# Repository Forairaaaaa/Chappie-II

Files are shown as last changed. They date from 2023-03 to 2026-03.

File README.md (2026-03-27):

# Chappie-II

基于ESP32的简易掌上终端~

视频介绍：https://www.bilibili.com/video/BV1QL411S7jo

硬件开源链接：https://oshwhub.com/eda_rgprdhwej/chappie2

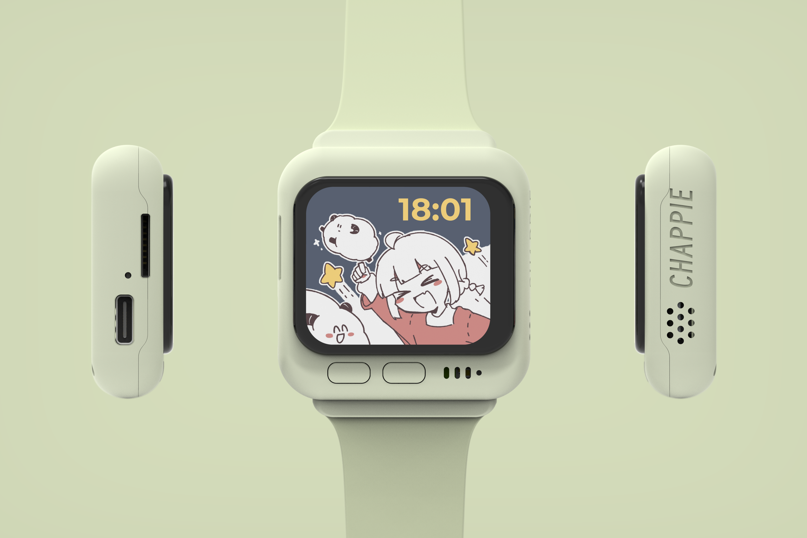
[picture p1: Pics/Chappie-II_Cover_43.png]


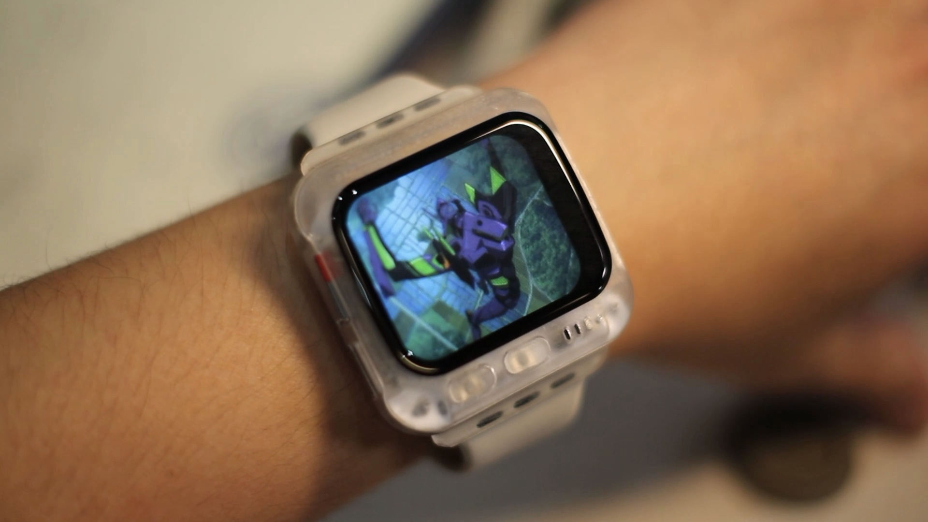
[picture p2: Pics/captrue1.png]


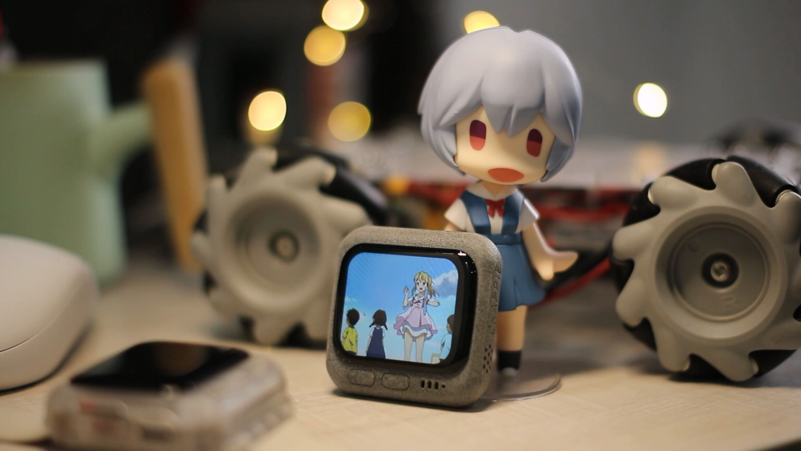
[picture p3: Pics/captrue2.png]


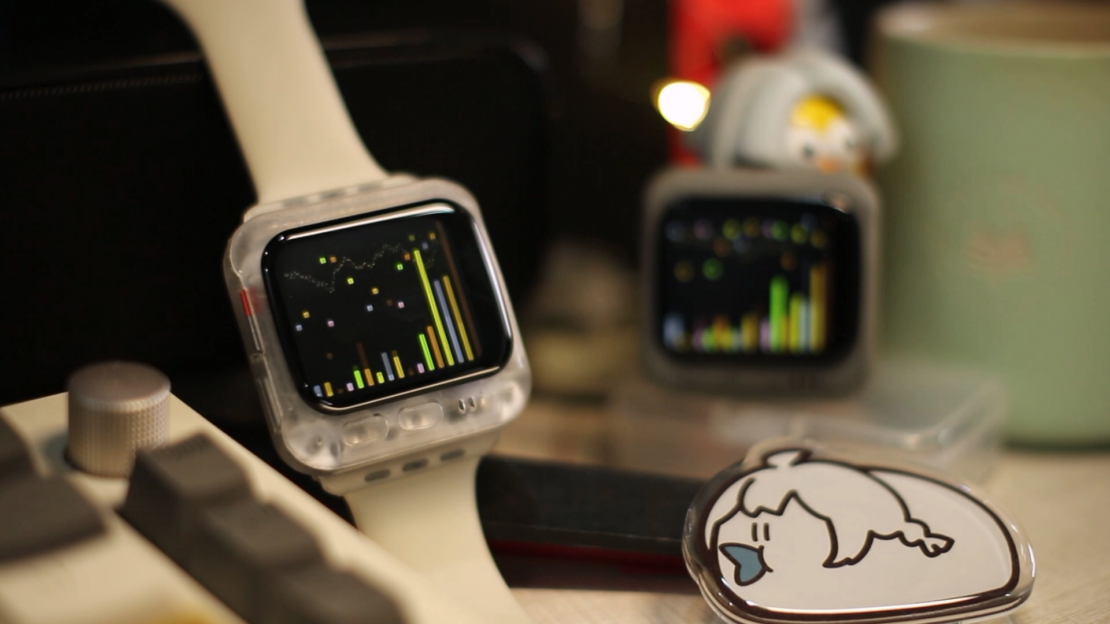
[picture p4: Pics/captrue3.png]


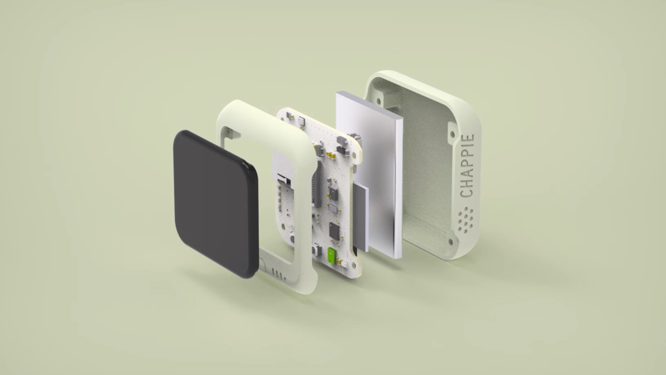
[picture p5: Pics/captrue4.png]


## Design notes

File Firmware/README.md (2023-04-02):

工程为PIO工程，vscode安装PIO扩展后打开文件夹即可

#### 文件树

```
Chappie-II/
├── default_16MB.csv
├── lib
│   ├── arduinoFFT
│   ├── ESP32-BLE-Gamepad
│   ├── FastLED
│   ├── LovyanGFX
│   ├── lv_conf.h
│   ├── lvgl
│   ├── NimBLE-Arduino
│   └── README
├── platformio.ini
├── src
    ├── ChappieBsp
    ├── ChappieUI
    └── main.cpp

```

#### 下载依赖

```shell
git submodule init
git submodule update
```

```shell
cd lib
git clone https://github.com/lovyan03/LovyanGFX.git
git clone -b v8.3.5 https://github.com/lvgl/lvgl.git
git clone https://github.com/FastLED/FastLED.git
git clone https://github.com/lemmingDev/ESP32-BLE-Gamepad.git
git clone https://github.com/h2zero/NimBLE-Arduino.git
git clone https://github.com/kosme/arduinoFFT.git
```

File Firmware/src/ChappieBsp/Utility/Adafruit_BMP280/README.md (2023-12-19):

# Adafruit BMP280 Driver (Barometric Pressure Sensor) 

This driver is for the [Adafruit BMP280 Breakout](http://www.adafruit.com/products/2651)



## About the BMP280 ##

This precision sensor from Bosch is the best low-cost sensing solution for measuring barometric pressure and temperature. Because pressure changes with altitude you can also use it as an altimeter!

## About this Driver ##

Adafruit invests time and resources providing this open source code.  Please support Adafruit and open-source hardware by purchasing products from Adafruit!

Written by Kevin (KTOWN) Townsend for Adafruit Industries.

<!-- START COMPATIBILITY TABLE -->

## Compatibility

MCU                | Tested Works | Doesn't Work | Not Tested  | Notes
------------------ | :----------: | :----------: | :---------: | -----
Atmega328 @ 16MHz  |      X       |             |            |
Atmega328 @ 12MHz  |      X       |             |            |
Atmega32u4 @ 16MHz |      X       |             |            | Use SDA/SCL on pins D2 &amp; D3
Atmega32u4 @ 8MHz  |      X       |             |            | Use SDA/SCL on pins D2 &amp; D3
ESP8266            |      X       |             |            | SDA/SCL default to pins 4 &amp; 5 but any two pins can be assigned as SDA/SCL using Wire.begin(SDA,SCL)
Atmega2560 @ 16MHz |      X       |             |            | Use SDA/SCL on pins 20 &amp; 21
ATSAM3X8E          |      X       |             |            | Use SDA/SCL on pins 20 &amp; 21
ATSAM21D           |      X       |             |            |
ATtiny85 @ 16MHz   |             |      X       |            |
ATtiny85 @ 8MHz    |             |      X       |            |
Intel Curie @ 32MHz |             |             |     X       |
STM32F2            |             |             |     X       |

  * ATmega328 @ 16MHz : Arduino UNO, Adafruit Pro Trinket 5V, Adafruit Metro 328, Adafruit Metro Mini
  * ATmega328 @ 12MHz : Adafruit Pro Trinket 3V
  * ATmega32u4 @ 16MHz : Arduino Leonardo, Arduino Micro, Arduino Yun, Teensy 2.0
  * ATmega32u4 @ 8MHz : Adafruit Flora, Bluefruit Micro
  * ESP8266 : Adafruit Huzzah
  * ATmega2560 @ 16MHz : Arduino Mega
  * ATSAM3X8E : Arduino Due
  * ATSAM21D : Arduino Zero, M0 Pro
  * ATtiny85 @ 16MHz : Adafruit Trinket 5V
  * ATtiny85 @ 8MHz : Adafruit Gemma, Arduino Gemma, Adafruit Trinket 3V

<!-- END COMPATIBILITY TABLE -->

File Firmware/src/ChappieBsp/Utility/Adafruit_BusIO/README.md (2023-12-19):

# Adafruit Bus IO Library 

This is a helper library to abstract away I2C & SPI transactions and registers

Adafruit invests time and resources providing this open source code, please support Adafruit and open-source hardware by purchasing products from Adafruit!

MIT license, all text above must be included in any redistribution

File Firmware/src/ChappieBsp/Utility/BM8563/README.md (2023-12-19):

Thanks to: https://github.com/tanakamasayuki/I2C_BM8563.git

# I2C BM8563 RTC Library

This is a library of BM8563, the RTC for I2C connectivity.

## Support Devices

- [M5Stack M5Stick](https://docs.m5stack.com/#/en/core/m5stickc)
- [M5Stack M5Stick Plus](https://docs.m5stack.com/#/en/core/m5stickc_plus)
- [M5Stack Core2](https://docs.m5stack.com/#/en/core/core2)
- [M5Stack Timer Camera](https://docs.m5stack.com/#/en/unit/timercam)
- [M5Stack Timer Camera X](https://docs.m5stack.com/#/en/unit/timercam_x)
- [M5Stack CoreInk](https://docs.m5stack.com/#/en/core/coreink)

## Usage
```c
#include "I2C_BM8563.h"
#include <WiFi.h>

// RTC BM8563 I2C port
// I2C pin definition for M5Stick & M5Stick Plus & M5Stack Core2 & M5Stack Core.Ink
#define BM8563_I2C_SDA 21
#define BM8563_I2C_SCL 22

// I2C pin definition for M5Stack TimerCam
// #define BM8563_I2C_SDA 12
// #define BM8563_I2C_SCL 14

I2C_BM8563 rtc(I2C_BM8563_DEFAULT_ADDRESS, Wire1);

const char* ntpServer = "time.cloudflare.com";

void setup() {
  // Init Serial
  Serial.begin(115200);
  delay(50);

  // Connect to an access point
  WiFi.begin();                 // Connect to the access point of the last connection
  //WiFi.begin("SSID", "KEY");  // Or, Connect to the specified access point

  Serial.print("Connecting to Wi-Fi ");
  while (WiFi.status() != WL_CONNECTED) {
    delay(500);
    Serial.print(".");
  }
  Serial.println(" CONNECTED");

  // Set ntp time to local
  configTime(9 * 3600, 0, ntpServer);

  // Init I2C
  Wire1.begin(BM8563_I2C_SDA, BM8563_I2C_SCL);

  // Init RTC
  rtc.begin();

  // Get local time
  struct tm timeInfo;
  if (getLocalTime(&timeInfo)) {
    // Set RTC time
    I2C_BM8563_TimeTypeDef timeStruct;
    timeStruct.hours   = timeInfo.tm_hour;
    timeStruct.minutes = timeInfo.tm_min;
    timeStruct.seconds = timeInfo.tm_sec;
    rtc.setTime(&timeStruct);

    // Set RTC Date
    I2C_BM8563_DateTypeDef dateStruct;
    dateStruct.weekDay = timeInfo.tm_wday;
    dateStruct.month   = timeInfo.tm_mon + 1;
    dateStruct.date    = timeInfo.tm_mday;
    dateStruct.year    = timeInfo.tm_year + 1900;
    rtc.setDate(&dateStruct);
  }
}

void loop() {
  I2C_BM8563_DateTypeDef dateStruct;
  I2C_BM8563_TimeTypeDef timeStruct;

  // Get RTC
  rtc.getDate(&dateStruct);
  rtc.getTime(&timeStruct);

  // Print RTC
  Serial.printf("%04d/%02d/%02d %02d:%02d:%02d\n",
                dateStruct.year,
                dateStruct.month,
                dateStruct.date,
                timeStruct.hours,
                timeStruct.minutes,
                timeStruct.seconds
               );

  // Wait
  delay(1000);
}
```

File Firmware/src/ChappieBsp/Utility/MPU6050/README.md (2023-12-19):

Thanks to: https://github.com/ElectronicCats/mpu6050.git



# MPU6050 by Electronic Cats

MPU-6050 6-axis accelerometer/gyroscope Arduino Library
adapted for Arduino Library Manager by Electronic Cats, Feb 2019

The MPU6050 combines a 3-axis gyroscope and a 3-axis accelerometer on the same silicon die together with
an onboard Digital Motion Processor(DMP) which processes complex 6-axis MotionFusion algorithms.

### Quick Installing

To install, use the Arduino Library Manager and search for "mpu6050" and install the library.

### Manual Installing
To install this library:

 - install it using the Arduino Library manager ("Sketch" -> "Include
   Library" -> "Manage Libraries..."), or
 - download a zipfile from github using the "Download ZIP" button and
   install it using the IDE ("Sketch" -> "Include Library" -> "Add .ZIP
   Library..."
 - clone this git repository into your sketchbook/libraries folder.

For more info, see https://www.arduino.cc/en/Guide/Libraries

## Features of this version

- Support for SAMD21 or ARM
- Support ESP32 and ESP8266
- Support for SAM

### Original Library

Based in the work of [jrowberg/i2cdevlib](https://github.com/jrowberg/i2cdevlib/tree/master/Arduino/MPU6050)

### Maintainer

<a href="https://github.com/sponsors/ElectronicCats">
  
</a>

Electronic Cats invests time and resources providing this open source design, please support Electronic Cats and open-source hardware by purchasing products from Electronic Cats!

### License

MIT

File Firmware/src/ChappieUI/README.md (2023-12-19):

# ChappieUI

基于[Lvgl](https://github.com/lvgl/lvgl)及[ChappieBsp](https://github.com/Forairaaaaa/ChappieBsp)的简单UI框架，UI框架实现简单App管理，启动器实现基础界面及App图形入口

使用`App_Generator.py`即可一键生成App：

```shell
python ./App_Generator.py
```

#### 文件树

```
ChappieUI/
├── Apps
│   ├── App_Dino
│   ├── App_ESPNOW
│   ├── App_FFT
│   ├── App_Gamepad
│   ├── App_Generator.py
│   ├── AppRegister.h
│   ├── App_Settings
│   ├── App_StupidSnake
│   ├── AppTypedef.h
│   ├── App_Watch
│   ├── App_WifiTV
│   └── Resource
├── ChappieUIConfigs.h
├── ChappieUI.cpp
├── ChappieUI.h
├── Launcher
    ├── App_Launcher.cpp
    ├── App_Launcher.h
    └── UI
```

#### App结构

```c++
/* App名字 */
std::string App_Template_appName();

/* App图标 */
void* App_Template_appIcon();

/* App创建回调 */
void App_Template_onCreate();

/* App循环回调 */
void App_Template_onLoop();

/* App结束回调 */
void App_Template_onDestroy();
```

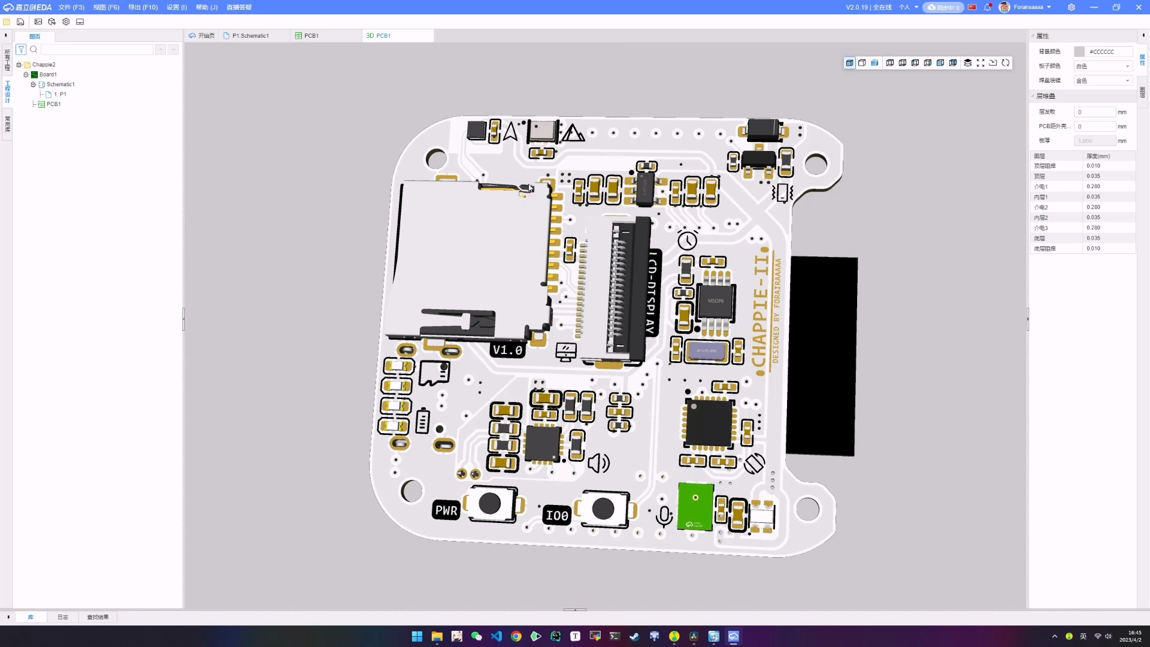
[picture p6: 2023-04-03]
Pics/captrue5.png

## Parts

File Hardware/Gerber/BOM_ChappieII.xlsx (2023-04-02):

No. | Quantity | Comment | Designator | Footprint | Value | Manufacturer Part | Manufacturer | Supplier Part | Supplier
1 | 2 | 47uF | C1,C6 | C0603 | 47uF | GRM188R60J476ME15D | muRata(村田) | C140782 | LCSC
2 | 7 | 22uF | C2,C7,C9,C10,C11,C12,C23 | C0603 | 22uF | CL10A226MP8NUNE | SAMSUNG(三星) | C86295 | LCSC
3 | 13 | 100nF | C3,C8,C13,C18,C19,C20,C21,C22,C24,C26,C28,C30,C33 | C0402 | 100nF | CC0402KRX7R7BB104 | YAGEO(国巨) | C60474 | LCSC
4 | 5 | 10uF | C4,C5,C16,C17,C25 | C0603 | 10uF | CL10A106KP8NNNC | SAMSUNG(三星) | C19702 | LCSC
5 | 2 | 18pF | C14,C15 | C0402 | 18pF | 0402CG180J500NT | FH(风华) | C1549 | LCSC
6 | 1 | 10nF | C27 | C0402 | 10nF | CC0402KRX7R9BB103 | YAGEO(国巨) | C60133 | LCSC
7 | 1 | 2.2nF | C29 | C0402 | 2.2nF | 0402B222K500NT | FH(风华) | C1531 | LCSC
8 | 2 | 220pF | C31,C32 | C0603 | 220pF | CL10B221KB8NNNC | SAMSUNG(三星) | C1603 | LCSC
9 | 1 | TF-01A | CARD1 | TF-SMD_TF-01A |  | TF-01A | 韩国韩荣 | C91145 | LCSC
10 | 1 | HC-1.25-2PWT | CN1 | CONN-SMD_2P-P1.25-HC-1.25-2PWT |  | HC-1.25-2PWT | HCTL(华灿天禄) | C2845379 | LCSC
11 | 1 | M1250R-02P | CN2 | CONN-TH_2P-P1.25_L4.7-W4.3 |  | M1250R-02P | XFCN(兴飞) | C481436 | LCSC
12 | 1 | USBLC6-2SC6 | D1 | SOT-23-6_L2.9-W1.6-P0.95-LS2.8-BL |  | USBLC6-2SC6 | TECH PUBLIC(台舟) | C2827654 | LCSC
13 | 1 | 1N4148W-7-F | D2 | SOD-123_L2.7-W1.6-LS3.7-RD-1 |  | 1N4148W-7-F | DIODES(美台) | C83528 | LCSC
14 | 1 | FPC-05F-18PH20 | FPC1 | FPC-SMD_18P-P0.50_FPC-05F-18PH20 |  | FPC-05F-18PH20 | XUNPU(讯普) | C2856802 | LCSC
15 | 2 | B-2202N20P-B121 | H1,H2 | HDR-SMD_20P-P2.00-V-R2-C10-S2.00-S6.0 |  | B-2202N20P-B121 | Ckmtw(灿科盟) | C135211 | LCSC
16 | 2 | TS-1088-AR02016 | KEY_DWN,KEY_PWR | SW-SMD_L4.0-W2.9-LS5.0 |  | TS-1088-AR02016 | XUNPU(讯普) | C720477 | LCSC
17 | 1 | TS24CA | KEY_RST | SW-SMD_TS24CA |  | TS24CA | SHOU HAN(首韩) | C393942 | LCSC
18 | 1 | 1uH | L1 | IND-SMD_L4.4-W4.2 | 1uH | MWSA0402S-1R0MT | Sunlord(顺络) | C408332 | LCSC
19 | 2 | 22uH | L2,L3 | L0603 | 22uH | CMI160808J220KT | FH(风华) | C361669 | LCSC
20 | 1 | WS2812B-2020 | LED1 | LED-SMD_4P-L2.0-W2.0-TL_WS2812B-2020 |  | WS2812B-2020 | worldsemi | C965555 | LCSC
21 | 1 | Z3OC1T8219731 | M1 | VIBRATING-MOTOR-SMD_3P-C9900001680 |  | Z3OC1T8219731 | KOTL(金龙机电) | C2894731 | LCSC
22 | 1 | MSM261D4030H1CPM | MIC1 | MIC-SMD_8P-L4.0-W3.0_ZTS6231 |  | MSM261D4030H1CPM | MEMS(敏芯微) | C966942 | LCSC
23 | 4 | MHT192WDT-ICE | PWR_D1,PWR_D2,PWR_D3,PWR_D4 | LED0603-RD |  | MHT192WDT-ICE | MEIHUA(美华) | C389522 | LCSC
24 | 2 | AO3400A | Q1,Q2 | SOT-23-3_L2.9-W1.3-P1.90-LS2.4-BR |  | AO3400A | HUASHUO(华朔) | C700953 | LCSC
25 | 2 | 5.1kΩ | R1,R4 | R0402 | 5.1kΩ | 0402WGF5101TCE | UNI-ROYAL(厚声) | C25905 | LCSC
26 | 1 | 2Ω | R2 | R0402 | 2Ω | 0402WGF200KTCE | UNI-ROYAL(厚声) | C270630 | LCSC
27 | 1 | 100kΩ | R3 | R0402 | 100kΩ | RC0402FR-07100KL | YAGEO(国巨) | C60491 | LCSC
28 | 9 | 10kΩ | R5,R7,R11,R12,R13,R14,R15,R17,R23 | R0402 | 10kΩ | TR0402D10K0Q1025Z | EVER OHMS(天二科技) | C149898 | LCSC
29 | 1 | 500mΩ | R6 | R0603 | 500mΩ | 0603WAF500LT5E | UNI-ROYAL(厚声) | C45312 | LCSC
30 | 1 | 200kΩ | R8 | R0402 | 200kΩ | 0402WGF2003TCE | UNI-ROYAL(厚声) | C25764 | LCSC
31 | 1 | 100kΩ | R9 | R0402 | 100kΩ | 0402WGF1003TCE | UNI-ROYAL(厚声) | C25741 | LCSC
32 | 3 | 0Ω | R10,R19,R20 | R0603 | 0Ω | 0603WAF0000T5E | UNI-ROYAL(厚声) | C21189 | LCSC
33 | 1 | 10Ω | R16 | R0402 | 10Ω | 0402WGF100JTCE | UNI-ROYAL(厚声) | C25077 | LCSC
34 | 1 | 10Ω | R18 | R0603 | 10Ω | 0603WAF100JT5E | UNI-ROYAL(厚声) | C22859 | LCSC
35 | 1 | 1MΩ | R21 | R0603 | 1MΩ | SCR0603J1M | VO(翔胜) | C3017671 | LCSC
36 | 2 | 2.2kΩ | R22,R24 | R0402 | 2.2kΩ | 0402WGF2201TCE | UNI-ROYAL(厚声) | C25879 | LCSC
37 | 1 | AP2112K-3.3TRG1 | U1 | SOT-25-5_L3.0-W1.8-P0.95-LS3.0-BR |  | AP2112K-3.3TRG1 | DIODES(美台) | C51118 | LCSC
38 | 1 | IP5306 | U2 | ESOP-8_L4.9-W3.9-P1.27-LS6.0-BL-EP |  | IP5306 | INJOINIC(英集芯) | C181692 | LCSC
39 | 1 | BM8563EMA | U3 | MSOP-8_L3.0-W3.0-P0.65-LS5.0-BL |  | BM8563EMA | GATEMODE(捷茂微) | C269878 | LCSC
40 | 1 | BMM150 | U4 | WLCSP-12_L1.6-W1.6_BMM150 |  | BMM150 | Bosch(博世) | C171681 | LCSC
41 | 1 | BMP280 | U5 | WLGA-8_L2.5-W2.0-P0.65-TR_DPS422 |  | BMP280 | Bosch(博世) | C83291 | LCSC
42 | 1 | ESP32-S3-WROOM-1(N16R2) | U6 | WIRELM-SMD_ESP32-S3-WROOM-1 |  | ESP32-S3-WROOM-1(N16R2) | ESPRESSIF(乐鑫) | C2913205 | LCSC
43 | 1 | MAX98357AETE+T | U7 | TQFN-16_L3.0-W3.0-P0.50-BL-EP1.5 |  | MAX98357AETE+T | MAXIM(美信) | C910544 | LCSC
44 | 1 | MPU-6050 | U8 | QFN-24_L4.0-W4.0-P0.50-BL-EP2.7 |  | MPU-6050 | TDK InvenSense(应美盛) | C24112 | LCSC
45 | 1 | KH-TYPE-C-16P | USB1 | USB-C-SMD_KH-TYPE-C-16P |  | KH-TYPE-C-16P | kinghelm(金航标) | C709357 | LCSC
46 | 1 | 32.768kHz | X1 | OSC-SMD_L3.2-W1.5 | 32.768kHz | FC-135 32.7680KA-A | EPSON(爱普生) | C1669857 | LCSC

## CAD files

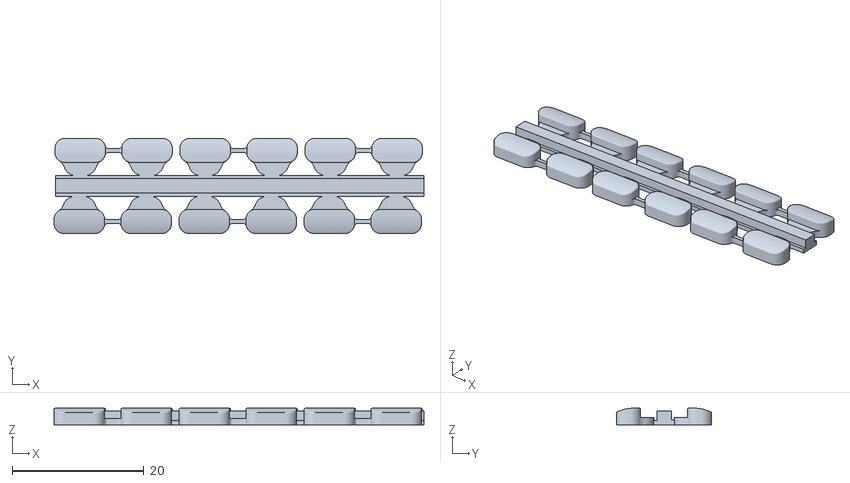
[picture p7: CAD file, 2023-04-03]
Modles/Chappie-II-button.stl
56.2 x 14.5 x 2.55

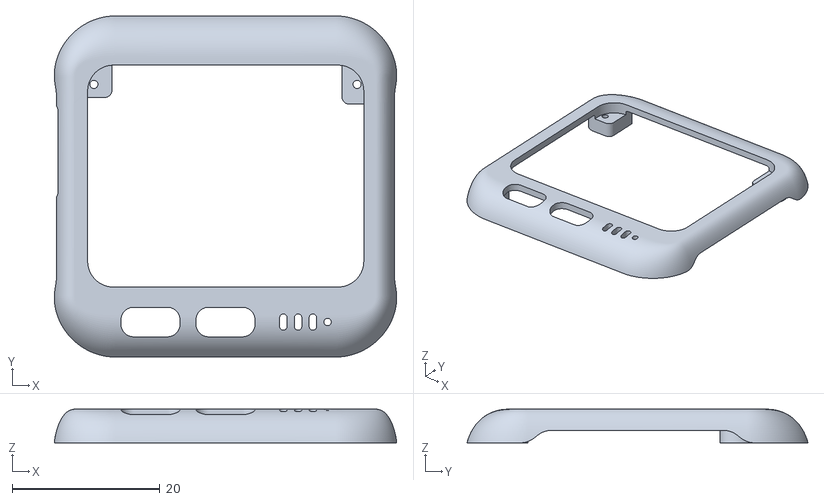
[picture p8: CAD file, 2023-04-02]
Modles/Chappie-II-top.stl
46.4 x 46.2 x 4.56

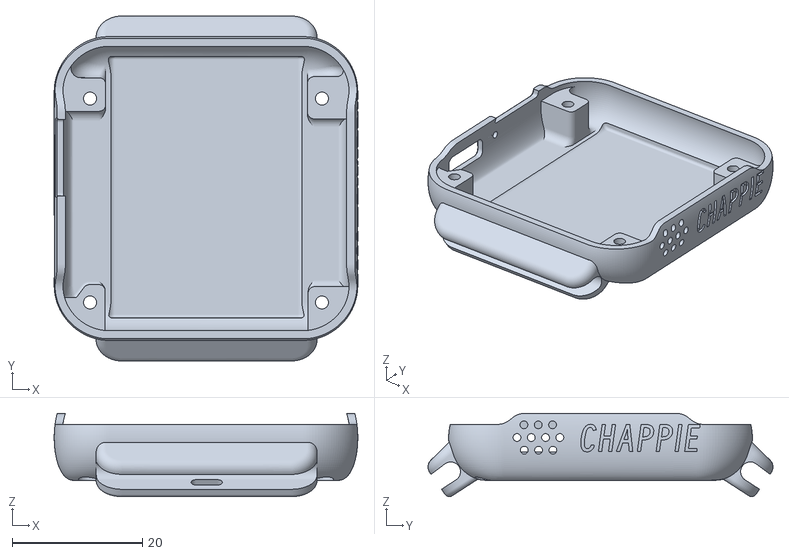
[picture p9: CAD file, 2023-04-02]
Modles/Chappie-II-bottom-watch.stl
46.7 x 53.1 x 12.8

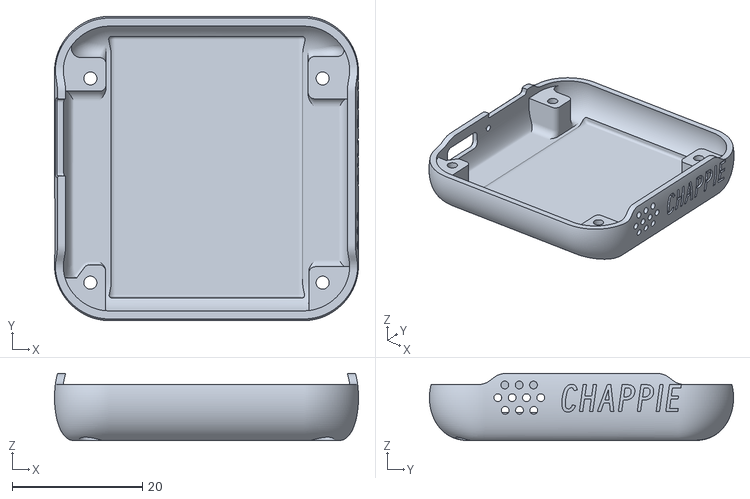
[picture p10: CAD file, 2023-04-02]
Modles/Chappie-II-bottom.stl
46.7 x 46.7 x 10.3

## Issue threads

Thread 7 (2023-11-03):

缺少ChappieUI.h

jiucheng008, 2023-11-03:
src/main.cpp:12:10: fatal error: ChappieUI/ChappieUI.h: No such file or directory
 #include "ChappieUI/ChappieUI.h"
          ^~~~~~~~~~~~~~~~~~~~~~~
compilation terminated.
*** [.pio\build\esp32s3box\src\main.cpp.o] Error 1

Closed 2023-11-03.

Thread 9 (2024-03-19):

ArduinoFFT库更新了2.0之后，git clone到lib目录之后编译报错，换成1.6.2版本后正常编译

mastwet, 2024-03-19:
RT，请作者修正相关代码或者更新拉取旧版的编译README。
相关变更：
[Version 2.0]
(https://github.com/kosme/arduinoFFT/releases/latest)
Use object templating.
Use camelCase for function names.
Add precompiler speed optimizations
Windowing factors storage

造成了旧版代码无法导入库的错误

Forairaaaaa, 2024-03-19:
_(:3 ⌒ﾞ)_

imhuangzhipeng, 2024-05-03:
这个issue还没关闭啊。。。

SilverYHZhang, 2025-04-18:
哥们，感谢你

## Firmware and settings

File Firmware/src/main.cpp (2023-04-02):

/**
 * @file main.cpp
 * @author Forairaaaaa
 * @brief 
 * @version 0.1
 * @date 2023-03-02
 * 
 * @copyright Copyright (c) 2023
 * 
 */
#include "Arduino.h"
#include "ChappieUI/ChappieUI.h"

CHAPPIEUI ChappieUI;

void setup()
{
    ChappieUI.begin();
}

void loop()
{
    ChappieUI.update();
    delay(5);
}

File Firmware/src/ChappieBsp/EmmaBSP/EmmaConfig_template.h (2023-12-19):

/**
 * @file EmmaConfig.h
 * @author Forairaaaaa
 * @brief 
 * @version 0.1
 * @date 2023-02-18
 * 
 * @copyright Copyright (c) 2023
 * 
 */
#pragma once
#if 0

/* Common configs */
#define EMMA_BSP_VERISON                "v3.2"
#define EMMA_PROJECT_NAME               "Emma"


/* Enable module Button */
#define EMMA_MODULE_BUTTON              1
#if EMMA_MODULE_BUTTON
    /* Set pin -1 to disable */
    #define EMMA_BTN_A_PIN              9
    #define EMMA_BTN_B_PIN              0
    #define EMMA_BTN_C_PIN              -1
    /* Add more button in "Button/EmmaButton.hpp" */
#endif


/* Enable module RGB led */
/* Require: https://github.com/FastLED/FastLED.git */
#define EMMA_MODULE_RGB_LED             1
#if EMMA_MODULE_RGB_LED
    #define EMMA_RGBLED_PIN             14
    #define EMMA_RGBLED_NUM             1
#endif


/* Enable module Buzzer */
#define EMMA_MODULE_BUZZER              0
#if EMMA_MODULE_BUZZER
    #define EMMA_BUZZER_PIN             2
    #define EMMA_BUZZER_MELODY          1
    #define EMMA_BUZZER_MELODY_MSG      1
    #define EMMA_BUZZER_MELODY_MUSIC    1
#endif


/* Enable module PDM Mic */
/* Use speaker class from M5Unified, thanks to @lovyan03 */
/* https://github.com/m5stack/M5Unified/blob/master/src/utility/Mic_Class.hpp */
#define EMMA_MODULE_MIC_PDM             1
#if EMMA_MODULE_MIC_PDM
    #define EMMA_MICPDM_CLK_PIN         6
    #define EMMA_MICPDM_DATA_PIN        7
    #define EMMA_MICPDM_I2S_PORT        I2S_NUM_0
    /* More configs in Mic/EmmaMicPDM.hpp */
#endif


/* Enable module Display */
/* Using https://github.com/lovyan03/LovyanGFX as GFX lib */
#define EMMA_MODULE_DISPLAY             1
#if EMMA_MODULE_DISPLAY
    /* Enable auto detect if supported */
    /* If not, setup your own config in Display/EmmaDisplay.hpp */
    #define EMMA_LGFX_AUTODETECT        0
    #if EMMA_LGFX_AUTODETECT
        #define LGFX_AUTODETECT
    #endif
#endif


/* Enable module Vibrator */
/* Simple viration motor control with ledc pwm */
#define EMMA_MODULE_VIBRATOR            1
#if EMMA_MODULE_VIBRATOR
    #define EMMA_VIBRATOR_PIN           46
#endif


/* Enable module Speaker */
/* Use speaker class from M5Unified, thanks to @lovyan03 */
/* https://github.com/m5stack/M5Unified/blob/master/src/utility/Speaker_Class.hpp */
/* Only wraped I2S mode so far */
#define EMMA_MODULE_SPEAKER             1
#if EMMA_MODULE_SPEAKER
    #define EMMA_SPEAKER_DATA_PIN       17
    #define EMMA_SPEAKER_BCLK_PIN       16
    #define EMMA_SPEAKER_LRCLK_PIN      15
    #define EMMA_SPEAKER_I2S_PORT       I2S_NUM_1
    /* Pin to shut down the speaker */
    #define EMMA_SPEAKER_ENABLE_PIN     3
    /* More configs in Speaker/EmmaSpeaker.hpp */
#endif

#endif

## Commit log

2023-04-02 add firmware source code
    [default_16MB.csv]
2023-04-03 add button
    [Chappie-II-button.stl]
